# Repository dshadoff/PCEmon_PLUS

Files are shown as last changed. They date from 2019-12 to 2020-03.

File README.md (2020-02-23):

# PCEmon_PLUS

This project is meant to enhance Chris Covell's PCEmon, which can be found here:
https://chrismcovell.com/PCEmon/index.html

This board implements a microcontroller (Adafruit Feather M0 Adalogger), to
simplify some operations and to generally make life easier for the PCEmon user.
Software is written using the Arduino IDE.

I am hoping that others find this useful, and are able to contribute to the
project in order to add new functionality.  I am open to improving the hardware
in future, if it would be helpful for the functionality added.

Features:
- Instead of swapping cables between joypad and computer, this board can change
which input is active, with the touch of a pad on the microcontroller board
- Currently, it powers up with a shell pass-thru interface with the original
PCEmon commands; touching the 'PLUS mode' touchpad on the board will bring up
an alternate interface which is being built, but can currently view and scroll
through main memory and VRAM (with more to come)

NOTES:
------
Recommended Teraterm settings by Setup menu area:
Terminal:
- New-line: Transmit - change to LF

Font:
- If you use Teraterm on Windows, I found that the default font is thin and wispy; a better
  font to use is "HGSoeiKakuGothicUB" (Regular)

Serial Port:
- Start with default 19200

Additional Settings, 'General' tab:
- Unset "Clear display when window resized"
- Set "Display serial port speed"

TODOs:
------
- Add interactive memory edit
- Add ZMODEM transfers for easier data handling
- Add disassembler (and save to SDCard/computer)
- Add more clever management of input control (i.e. PCE can signal back with
extended /CLR=high signal, that PCE is ready for PCEmoninput)

This is prototype software, and as such has been minimally tested.
Use at your own risk.

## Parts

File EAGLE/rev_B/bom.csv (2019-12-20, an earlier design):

Qty | Designator | Footprint | Comment | LCSC Part # (optional) | Description (optional)
5 | C6, C7, C8, C9, C10 | C0603 | 100nF 50V X7R | C14663 | MULTILAYER CERAMIC CAPACITORS MLCC - SMD/SMT 100NF 50V 0603 ROHS
6 | R13, R14, R15, R16, R17, R18 | R0603 | 300Ω 1% | C23025 | CHIP RESISTOR - SURFACE MOUNT 300OHMS ±1% 1/10W 0603 ROHS
2 | R1, R3 | R0603 | 4.7KΩ 1% | C23162 | CHIP RESISTOR - SURFACE MOUNT 4.7KOHMS ±1% 1/10W 0603 ROHS
10 | R2, R4, R5, R6, R7, R8, R9, R10, R11, R12 | R0603 | 47KΩ 1% | C25819 | CHIP RESISTOR - SURFACE MOUNT 47KOHMS ±1% 1/10W 0603 ROHS
2 | D1, D3 | CHIP-LED0603 | GREEN | C72043 | LIGHT EMITTING DIODES (LED) GREEN 520~535NM 112~258MCD@20MA TOP VIEW 0603 ROHS
1 | IC3 | SOIC-16_3.9x9.9x1.27P | 74HC157D,653 | C5609 | 74 SERIES MULTIPLEXERS 2V ~ 6V SOIC-16_150MIL ROHS
2 | IC1, IC2 | SM-8_2.8x3.0x0.65P | SN74LVC2T45DCTR | C22672 | 74 SERIES 1 1.65V ~ 5.5V SM8 ROHS
1 | J1 | 1x08_ROUND | pin header | Do not populate
2 | J2, J3 | MD80SGK | MD-80SGK | Do not populate
1 | JP3 | 1X12_ROUND | pin header | Do not populate
1 | JP1 | 1X16_ROUND | pin header | Do not populate

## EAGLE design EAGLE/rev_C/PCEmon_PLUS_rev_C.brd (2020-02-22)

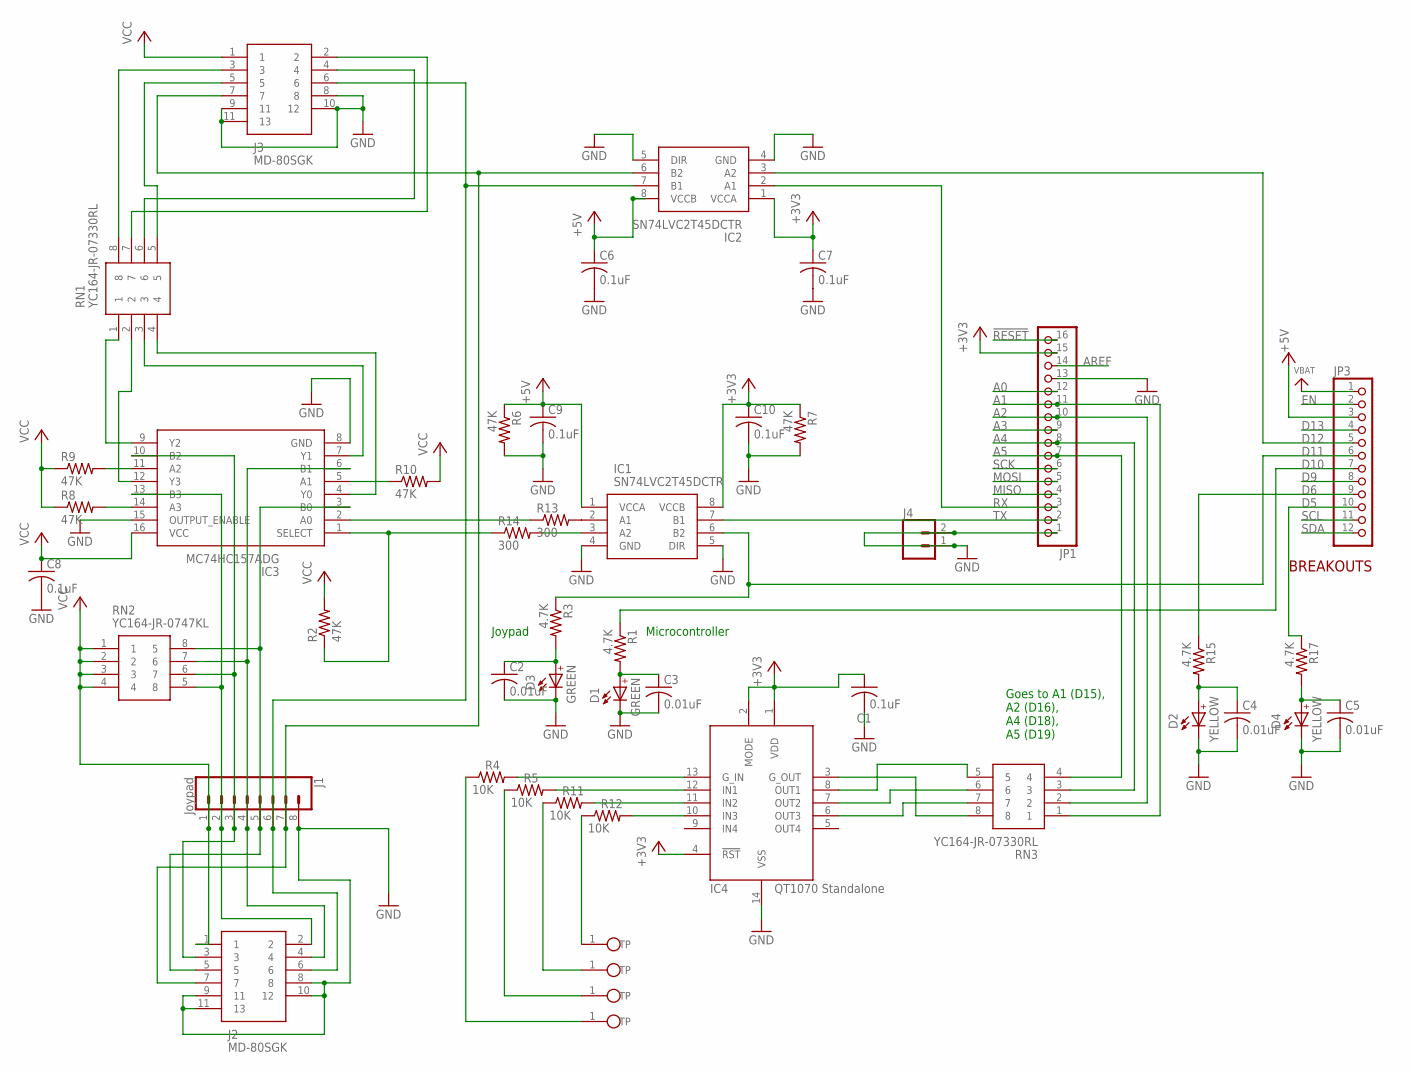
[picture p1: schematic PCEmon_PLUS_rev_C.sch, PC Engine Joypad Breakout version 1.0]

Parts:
C1, C6, C7, C8, C9, C10: 0.1uF; C0603
C2, C3, C4, C5: 0.01uF; C0603
D1, D3: GREEN; WL-SMCC_0603_R/Y/V
D2, D4: YELLOW; WL-SMCC_0603_R/Y/V
IC1, IC2: SN74LVC2T45DCTR; SOP65P400X130-8N
IC3: MC74HC157ADG; SOIC127P600X175-16N
IC4: AT42QT1070-SSU; SO14
J1: Joypad; 1X08
J2, J3: MD-80SGK; MD80SGK
J4: CONN_021X02_NO_SILK; 1X02_NO_SILK
JP1: HEADER-1X16ROUND; 1X16_ROUND
JP3: HEADER-1X12; 1X12_ROUND
P1: JOYPAD; TOUCH-350X500
P2: COMPUTER; TOUCH-350X500
P3: Original Mode; TOUCH-350X500
P4: PLUS Mode; TOUCH-350X500
R1, R3, R15, R17: 4.7K; R0603
R2, R6, R7, R8, R9, R10: 47K; R0603
R4, R5, R11, R12: 10K; R0603
R13, R14: 300; R0603
RN1, RN3: YC164-JR-07330RL; YC164JR07220RL
RN2: YC164-JR-0747KL; YC164JR07220RL

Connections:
!RESET: JP1.16
+3V3: C1.1, C7.1, C10.1, IC1.8 (VCCB), IC2.1 (VCCA), IC4.1 (VDD), IC4.2 (MODE), IC4.4 (!RST), JP1.15, R7.1
+5V: C6.1, C9.1, IC1.1 (VCCA), IC2.8 (VCCB), JP3.3, R6.1
A0: JP1.12
A1: JP1.11, RN3.1
A2: JP1.10, RN3.2
A3: JP1.9
A4: JP1.8, RN3.3
A5: JP1.7, RN3.4
AREF: JP1.14
D5: JP3.10, R17.1
D6: JP3.9, R15.1
D9: JP3.8
D10: JP3.7, R1.1
D11: IC1.6 (B2), JP3.6, R3.1
D12: IC2.3 (A2), JP3.5
D13: JP3.4
EN: JP3.2
GND: C1.2, C2.2, C3.2, C4.2, C5.2, C6.2, C7.2, C8.2, C9.2, C10.2, D1.1 (C), D2.1 (C), D3.1 (C), D4.1 (C), IC1.4 (GND), IC1.5 (DIR), IC2.4 (GND), IC2.5 (DIR), IC3.8 (GND), IC3.15 (OUTPUT_ENABLE), IC4.14 (VSS), J1.8, J2.8, J2.9 (11), J2.10 (12), J2.11 (13), J3.8, J3.9 (11), J3.10 (12), J3.11 (13), J4.1, J4.2, JP1.1, JP1.13, R6.2, R7.2
MISO: JP1.4
MOSI: JP1.5
unnamed: C2.1, D3.2 (A), R3.2
unnamed: IC3.10 (B2), J1.3, J2.3, RN2.6 (7)
unnamed: IC3.13 (B3), J1.2, J2.2, RN2.5 (8)
unnamed: IC3.6 (B1), J1.4, J2.4, RN2.7 (6)
unnamed: IC3.3 (B0), J1.5, J2.5, RN2.8 (5)
unnamed: IC2.7 (B1), J1.6, J2.6, J3.6
unnamed: IC2.6 (B2), J1.7, J2.7, J3.7
unnamed: J3.5, RN1.5
unnamed: C3.1, D1.2 (A), R1.2
unnamed: J3.4, RN1.6
unnamed: J3.3, RN1.8
unnamed: IC3.14 (A3), R8.2
unnamed: IC3.11 (A2), R9.2
unnamed: IC3.1 (SELECT), R2.1, R14.1
unnamed: IC1.2 (A1), R13.2
unnamed: IC3.5 (A1), R10.1
unnamed: IC3.9 (Y2), RN1.1
unnamed: IC3.2 (A0), R13.1
unnamed: IC1.3 (A2), R14.2
unnamed: IC3.12 (Y3), RN1.2
unnamed: IC4.13 (G_IN), R4.2
unnamed: IC3.4 (Y0), RN1.4
unnamed: J3.2, RN1.7
unnamed: IC3.7 (Y1), RN1.3
unnamed: IC4.12 (IN1), R5.2
unnamed: IC4.11 (IN2), R11.2
unnamed: IC4.10 (IN3), R12.2
unnamed: IC4.3 (G_OUT), RN3.8
unnamed: IC4.6 (OUT3), RN3.7
unnamed: IC4.7 (OUT2), RN3.6
unnamed: IC4.8 (OUT1), RN3.5
unnamed: P3.1, R5.1
unnamed: P4.1, R4.1
unnamed: P2.1, R11.1
unnamed: P1.1, R12.1
unnamed: C4.1, D2.2 (A), R15.2
unnamed: C5.1, D4.2 (A), R17.2
RX: IC2.2 (A1), JP1.3
SCK: JP1.6
SCL: JP3.11
SDA: JP3.12
TX: IC1.7 (B1), JP1.2
VBAT: JP3.1
VCC: C8.1, IC3.16 (VCC), J1.1, J2.1, J3.1, R2.2, R8.1, R9.1, R10.2, RN2.1, RN2.2, RN2.3, RN2.4

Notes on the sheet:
BREAKOUTS
Joypad
Microcontroller
Goes to A1 (D15), A2 (D16), A4 (D18), A5 (D19)

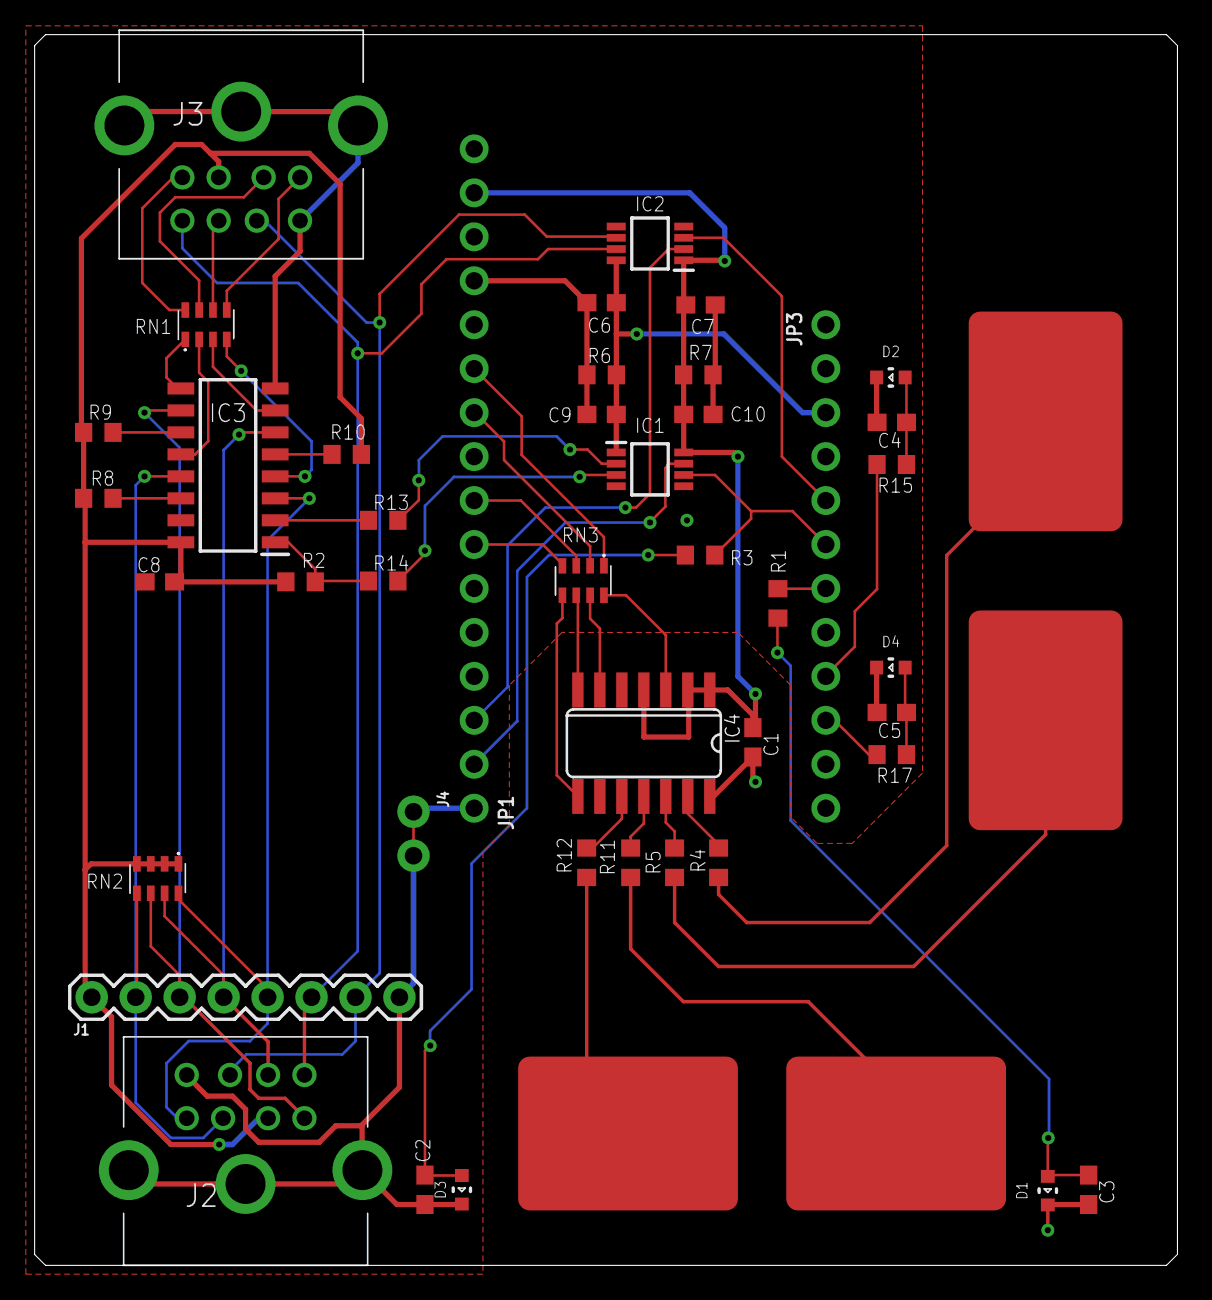
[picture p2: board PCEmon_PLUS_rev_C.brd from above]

Board: 2 copper layers, 66.0 x 71.1 mm, 47 parts (0 on the bottom side), 52 nets.

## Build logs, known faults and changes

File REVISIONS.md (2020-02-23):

# REVISIONs

20200222:
- Added 'rev. C' board design to the repository
- modified code to accept touch input from teh board instead of keyboard
  commands for switching inputs or modes
- Added recommended Teraterm settings for best results to the README.md file

20200118:
- added scroll left/right (1-byte movement)
- added "Address" entry command
- fix bugs; minor formatting changes

20200105:
- added flag display
- added VRAM display
- started implementing commands ("View" in this case)
- cleaned up the key fetch framework a bit
- various minor changes
- added help text 

20191231:
- bugs and improvements
- add some (but not enough) help text
- add some color to theme
- add communication flip to PCE-to-MCU during debug 

20191229:
- added more framework
- split interface between traditional and new interaction modes
- program now grabs downloads into buffers
- memory view/scroll now working

20191219:
- check in Rev. B boards
- bom.csv and assembly.csv were required by JLCPCB in order to do the SMT assembly

20191216:
- sync up echo
- add 1-button BRAM fetch (temporary framing)
- Make direction of data clearer for PCE communications

20191214:
- Initial check-in of rev. A boards.  Fair power isolation between PC and PCE, but
boot-up of MCU causes garbage input on the PCE side.
- Currently, only a shell pass-thru interface with trivial commands are implemented
(including input-swapping), with more to come once the rev. B boards are received
and verified

This is prototype software, and as such has been minimally tested.
Use at your own risk.

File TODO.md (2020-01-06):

# TODO (feature requests):

- Add interactive memory edit
- Add ZMODEM transfers for easier data handling
- Add disassembler (and save to SDCard/computer)
- Add more clever management of input control (i.e. PCE can signal back with
extended /CLR=high signal, that PCE is ready for PCEmoninput)
- Memory compare: take a snapshot, and compare later (to spot changes in BRAM for example)

This is prototype software, and as such has been minimally tested.
Use at your own risk.

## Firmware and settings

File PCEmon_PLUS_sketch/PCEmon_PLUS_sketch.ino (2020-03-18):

/*
  PCEmon_PLUS sketch

  On most boards (including the Adafruit M0 Adalogger), "Serial" refers to the USB
  Serial port attached to the Serial Monitor, and "Serial1" refers to the hardware
  serial port attached to pins 0 and 1. This sketch will emulate Serial passthrough
  using those two Serial ports on the boards mentioned above, but you can change
  these names to connect any two serial ports on a board that has multiple ports.

  This version of the sketch is intended for "rev. C" of the board

  (c) 2019, 2020 by David Shadoff
*/

// Strictly speaking, "Serial1" is used to communicate to the PCE side
// However, when written in code, that is nearly identical to "Serial"
// which is the Terminal side, so confusion can result.
//
// I am using an alias of "PCE" to help reduce this confusion even
// though syntax highlighting doesn't show it in the same way as Serial1
//


#include <SD.h>

#include "define.h"
#include "common.h"
#include "escape.h"

extern void altLoop();
extern void setAltMode();

File dataFile;


void setup()
{
  int i;
  char c;

  // setup Serial ports
  Serial.begin(19200);  // computer side
  PCE.begin(19200); // PCE Side

  // setup GPIO pins
  pinMode(joypadPin,   OUTPUT);
  pinMode(computerPin, OUTPUT);
  pinMode(attnPin,     INPUT);

  digitalWrite(joypadPin,   LOW);  // switch PCE to computer input (not joypad)
  digitalWrite(computerPin, HIGH); // 

  digitalWrite(plusModeLEDPin, LOW);  // switch PCE to original mode 
  digitalWrite(origModeLEDPin, HIGH); // 

  // Detect and initialze SDCard access hardware
  cardPresent = true;
  if (!SD.begin(chipSelect)) {
    Serial.println("Card failed or not present");
    cardPresent = false;
  }

  drainSerialQueue();
  modeMonitor = false;

  // detect echo on PCE side
  PCE_Echo = false;
  PCE.print("O");
  delay(100);

  // This implements a timeout; the above letter is sent,
  // and may or may not be echoed... we briefly listen for
  // the echo in order to determine whether echo is ON at
  // the time of microcontroller startup
  
  while (i < 100) {
    if (PCE.available()) {
      c = PCE.read();
      if (c == 'O') {
        PCE_Echo = true;
        break;
      }
    }
    i++;
    delay(1);
  }

  // if echo is off, turn it on
  if (PCE_Echo == false)
    PCE.println(" E");
  else
    PCE.println("");

  PCE_Echo = true;
}


//
// Add some instructions to 'accelerate' the grab/download of BRAM data
// as an example of what can be done as part of acceleration
//
// This function will be relocated to the "alternate commands" side soon
//
void getbram()
{
int i;
int c;

  if (cardPresent) {
    if (SD.exists("BRAM.sav")) {
      Serial.println("mb128.sav exists; removing");
      SD.remove("BRAM.sav");
    }

    Serial.println("Opening BRAM.sav");
    dataFile = SD.open("BRAM.sav", FILE_WRITE);
  }

  Serial.println("Get BRAM:");
  switchPCEInput(COMPUTER_IN);
  
  // if echo was on, temporarily disable echo
  //
  if (PCE_Echo == true) {
    PCE.println("O E");
    drainSerialQueue();  // consume the response
  }

  PCE.println("<");
  delay(200);
  PCE.println("S");

  i = 0;
  while (i < 2048) {
    if (PCE.available()) {
      c = PCE.read();
      if (cardPresent)
        dataFile.write(c);
      else
        Serial.write(c);
      i++;
    }
  }

  if (cardPresent)
    dataFile.close();
    
  // if echo was originally on, re-enable echo
  //
  if (PCE_Echo == true) {
    PCE.println("O E");
    drainSerialQueue();  // consume the response
  }

  Serial.println("done");
}

void loop() {
int c;
int a1, a2, a4;
const int touchThreshold = 100;
int numbytes, readsize, bytesread;
boolean flush = false;
char buffer[49];

  if (modeMonitor == true) {
    altLoop();
    return;
  }
 
  a1 = analogRead(joyTouchPin);
  a2 = analogRead(compTouchPin);
  a4 = analogRead(plusModeTouchPin);

  // deal with touchpad inputs
  //
  if (a1 < touchThreshold)
    switchPCEInput(JOYPAD_IN);

  else if (a2 < touchThreshold)
    switchPCEInput(COMPUTER_IN);

  else if (a4 < touchThreshold) {
    modeMonitor = true;
    setAltMode();
  }

  if (Serial.available()) {      // If anything comes in Serial (USB),
    c = Serial.read();

//  Filtering inputs was found to be a problem in a previous version,
//  so all input filtering is now removed, and the job of the touchpads
//  on the PC board
//
//    if (c == 'Z')
//      getbram();
//    else {
//    }
    switchPCEInput(COMPUTER_IN);
    PCE.write(c);   // read it and send it out Serial1 (pins 0 & 1)
    return;
  }

  delay(4);                               // pause to prevent more than 250 USB packets per second

  numbytes = PCE.available();
  if (numbytes > 0) {                     // If anything comes in Serial1 (pins 0 & 1)
    readsize = min(48, numbytes);
    bytesread = PCE.readBytes(buffer, readsize);
    Serial.write(buffer, bytesread);      // read it and send it out Serial (USB)
    flush = true;
  }
  else if (flush == true) {
    Serial.flush();
    flush = false;
  }
}

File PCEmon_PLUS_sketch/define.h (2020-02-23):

//
// define.h
//
// Common Definitions file used by everybody
//
// (c) 2019, 2020 by David Shadoff

#define PCE     Serial1


#define JOYPAD_IN    0
#define COMPUTER_IN  1

// names of keys
// Note that any multi-code key has special code defined here
//
// single-code keystrokes:
#define KEY_BACKSPACE    0x08
#define KEY_TAB          0x09
#define KEY_ENTER        0x0A
#define KEY_ESCAPE       0x1B
#define KEY_DELETE       0x7F

// multi-code keystrokes:

#define KEY_F1           0xFF01    // 0x1B 0x5B 0x31 0x31 0x7E via serial
#define KEY_F2           0xFF02    // 0x1B 0x5B 0x31 0x32 0x7E via serial
#define KEY_F3           0xFF03    // 0x1B 0x5B 0x31 0x33 0x7E via serial
#define KEY_F4           0xFF04    // 0x1B 0x5B 0x31 0x34 0x7E via serial
#define KEY_F5           0xFF05    // 0x1B 0x5B 0x31 0x35 0x7E via serial
#define KEY_F6           0xFF06    // 0x1B 0x5B 0x31 0x37 0x7E via serial
#define KEY_F7           0xFF07    // 0x1B 0x5B 0x31 0x38 0x7E via serial
#define KEY_F8           0xFF08    // 0x1B 0x5B 0x31 0x39 0x7E via serial
#define KEY_F9           0xFF09    // 0x1B 0x5B 0x32 0x30 0x7E via serial
#define KEY_F10          0xFF0A    // 0x1B 0x5B 0x32 0x31 0x7E via serial
#define KEY_F11          0xFF0B    // 0x1B 0x5B 0x32 0x33 0x7E via serial
#define KEY_F12          0xFF0C    // 0x1B 0x5B 0x32 0x34 0x7E via serial

#define KEY_HOME         0xFF31    // 0x1B 0x5B 0x31 0x7E via serial
#define KEY_INSERT       0xFF32    // 0x1B 0x5B 0x32 0x7E via serial
#define KEY_END          0xFF34    // 0x1B 0x5B 0x34 0x7E via serial
#define KEY_PAGEUP       0xFF35    // 0x1B 0x5B 0x35 0x7E via serial
#define KEY_PAGEDOWN     0xFF36    // 0x1B 0x5B 0x36 0x7E via serial

#define KEY_UPARROW      0xFF41    // 0x1B 0x5B 0x41 via serial
#define KEY_DOWNARROW    0xFF42    // 0x1B 0x5B 0x42 via serial
#define KEY_RIGHTARROW   0xFF43    // 0x1B 0x5B 0x43 via serial
#define KEY_LEFTARROW    0xFF44    // 0x1B 0x5B 0x44 via serial

#define KEY_NUMLOCK      0xFF50    // 0x1B 0x4F 0x50 via serial
#define KEY_BACKTAB      0xFF5A    // 0x1B 0x5B 0x5A via serial



// This sketch is made specifically for the Adafruit M0 Feather Adalogger


// input pins:
//
const int joyTouchPin      = A2;
const int compTouchPin     = A4;
const int origModeTouchPin = A5;
const int plusModeTouchPin = A1;

const int attnPin      = 12;  // joypad CLR pin.
                              // Future proposed functionality:
                              //   if PC-E sets this high for >16ms,
                              //   it is a signal to switch back to MCU mode

                              
// output pins:
//
const int origModeLEDPin  = 5;   // Drives LED displaying original mode 
const int plusModeLEDPin  = 6;   // Drives LED displaying PLUS mode

const int joypadPin    = 11;  // if set high, triggers joypad passthru to port
const int computerPin  = 10;  // This should be the inverse of joypadPin (status LED)


// miscellaneous pins:
//
const int chipSelect   = 4;   // Pin used for chip select for on-board SDCard

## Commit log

2019-12-17 Added: - echo synchronization - 1-button BRAM backup - slightly clearer view of data direction (PCE versus Serial1)
2019-12-20 Add Rev. B boards into repo bom.csv and assembly.csv were files needed by JLCPCB SMT assembly
    [PCEmon_PLUS_rev_A.brd, PCEmon_PLUS_rev_A.sch, PCEmon_PLUS_rev_B.brd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]
2019-12-29 Add more framework; communications and memory view/scroll now working
2019-12-31 Various bug fixes & improvements; improve help text and give some color
    [PCEmon_PLUS_sketch.ino, alternate.cpp, escape.h]
2020-01-06 - added flag display, VRAM display - started implementing commands ("View" in this case) - various minor fixes and improvements
    [PCEmon_PLUS_sketch.ino, alternate.cpp, common.cpp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]
2020-01-18 add 'Address' command, 1-byte scroll movements; fix bugs, adjust formatting
    [PCEmon_PLUS_sketch.ino, alternate.cpp, common.cpp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]
2020-02-22 Add new 'rev. C' board design,
    Add new 'rev. C' board design with touch sensros to switch inputs and monitor modes
    [PCEmon_PLUS_rev_C.brd, PCEmon_PLUS_rev_C.sch]
2020-02-23 Update to Rev. C boards
    - update boards to revision C
    - adjust code to make use of touchpads instead of key commands to switch inputs or operating modes
    - add recommended Teraterm settings
2020-06-06 Fix register alignment
    Fix register alignment
    [alternate.cpp]

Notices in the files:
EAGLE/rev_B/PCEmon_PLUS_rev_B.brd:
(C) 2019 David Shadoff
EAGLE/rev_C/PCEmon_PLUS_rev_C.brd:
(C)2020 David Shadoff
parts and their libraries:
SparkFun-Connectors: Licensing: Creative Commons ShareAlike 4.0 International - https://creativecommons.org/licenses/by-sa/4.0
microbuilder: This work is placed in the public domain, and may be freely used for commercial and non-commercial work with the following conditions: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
